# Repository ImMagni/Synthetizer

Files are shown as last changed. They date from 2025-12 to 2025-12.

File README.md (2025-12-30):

# Synthesizer 
A Synthesizer piano with three octaves that uses an Orpheus Pico, PCM5100 DAC, LM4810, and PAM8403 amplifiers.
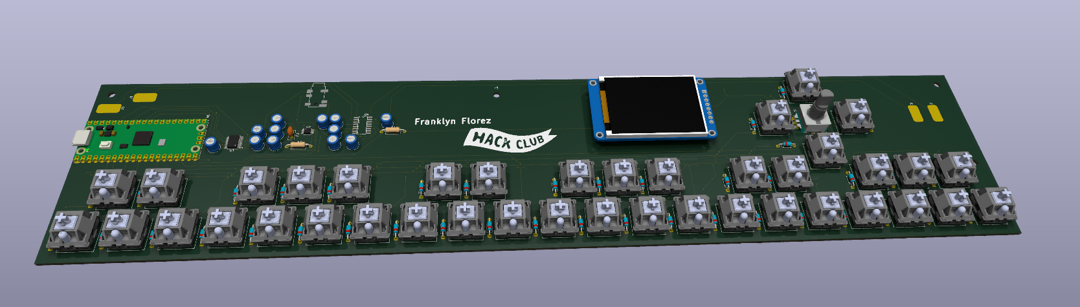
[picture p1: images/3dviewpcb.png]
 <br>

This project is a digital synthesizer keyboard capable of generating audio internally or outputting MIDI over USB. It features a screen-based user interface controlled through a rotary encoder and directional buttons.
## Features
- Volume control from the screen using a rotary encoder
- Selectable output modes: MIDI, Speakers, or Line output
- Three-octave keyboard
- Multiple waveform generation modes for audio
- Settings saves on memory
- On-screen menu system with directional navigation
- LCD feedback for current settings
## BOM
- 1× Orpheus_Pico (Raspberry Pi Pico)
- 5× Capacitor 1 µF
- 4× Capacitor 4.7 µF
- 1× Capacitor 0.1 µF
- 1× Capacitor 0.1 µF
- 2× Capacitor 10 µF
- 41× Diode 1N4148
- 1× screen ST7735R LCD
- 1× Jack audio 3.5 mm
- 2× Resistencia 10 kΩ
- 40× Cherry Switchs
- 1× Rotary Encoder with switch
- 1× PCM5100 DAC
- 1× LM4810
- 1x PAM8403
- 5x M3 Heatsets
- 5x M3x16 screws

Case|Schematic|Pcb
:-:|:-:|:-:|
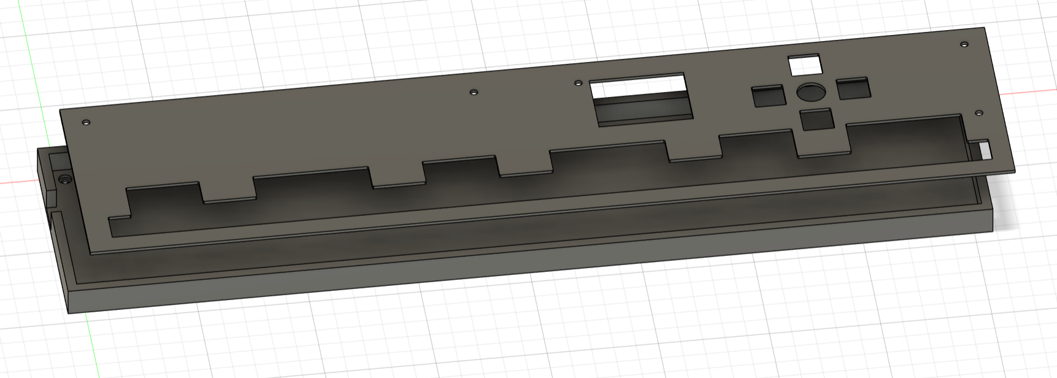
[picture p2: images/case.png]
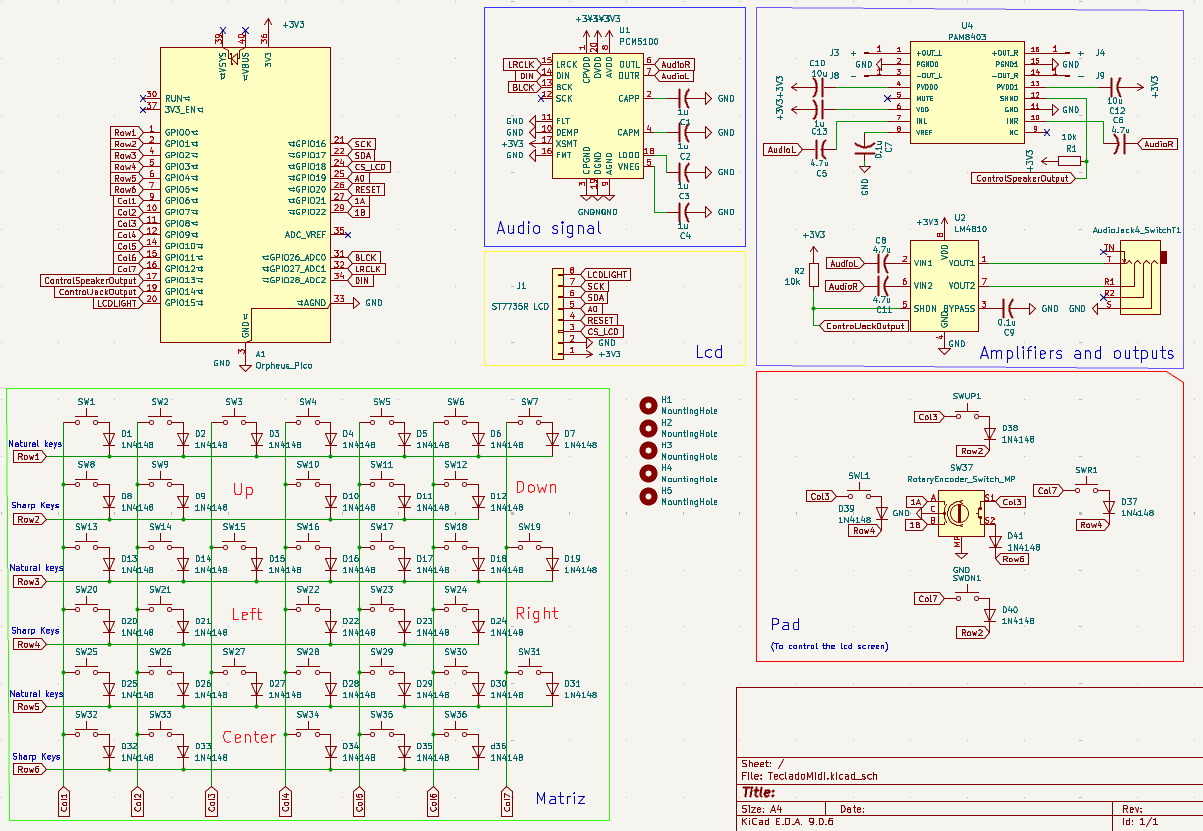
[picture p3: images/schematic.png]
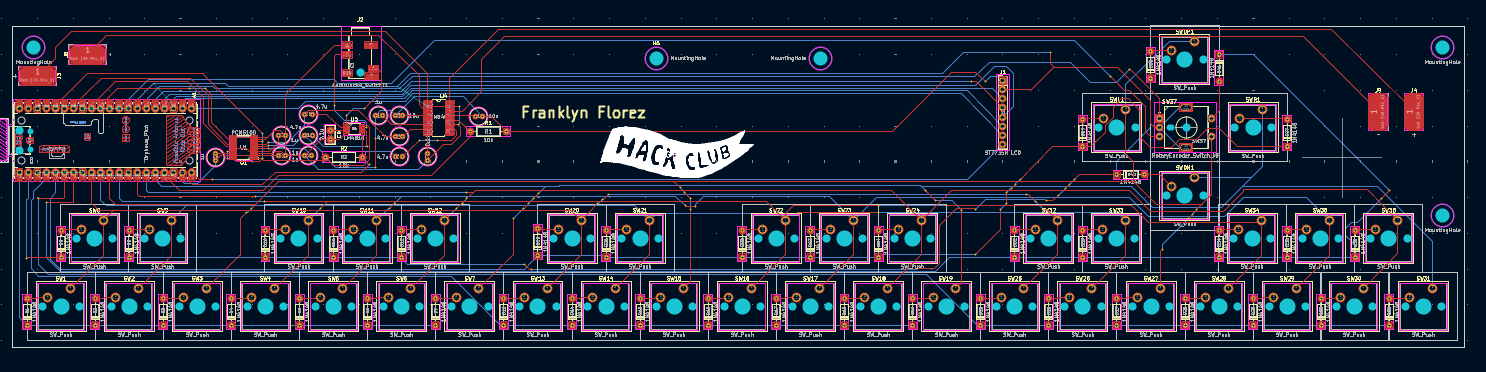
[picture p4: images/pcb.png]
|| 

-|-
:-:|:-:|
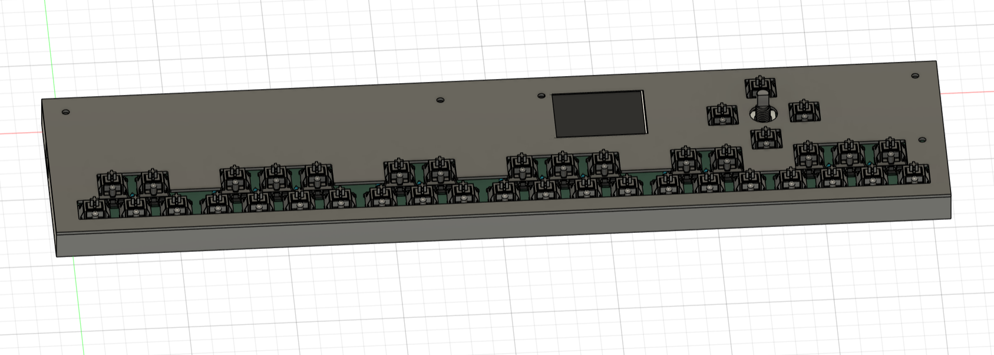
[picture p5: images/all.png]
|

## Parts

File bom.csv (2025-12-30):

Reference | Value | Footprint | Product Amount | Do i have it? | It comes in the kit? | Product Cost |  | link
Orpheus_Pico |  | Module:RaspberryPi_Pico_Common_Unspecified | 1 | No | Yes
Capacitor | 1u | Capacitor_THT:C_Radial_D5.0mm_H5.0mm_P2.00mm | 5 | No | Yes
Capacitor | 4.7u | Capacitor_THT:C_Radial_D5.0mm_H5.0mm_P2.00mm | 4 | No | Yes
Capacitor | 0.1u | Capacitor_THT:C_Radial_D5.0mm_H5.0mm_P2.00mm | 1 | No | Yes
Capacitor | 0.1u | Capacitor_THT:C_Disc_D5.0mm_W2.5mm_P2.50mm | 1 | No | Yes
Capacitor | 10u | Capacitor_THT:C_Radial_D5.0mm_H5.0mm_P2.00mm | 2 | No | Yes
1N4148 |  | Diode_THT:D_DO-35_SOD27_P7.62mm_Horizontal | 41 | No | Yes
ST7735R LCD |  | Connector_PinHeader_2.54mm:PinHeader_1x08_P2.54mm_Vertical | 1 | No | Yes
resistor | 10k | Resistor_THT:R_Axial_DIN0207_L6.3mm_D2.5mm_P10.16mm_Horizontal | 2 | No | Yes
Cherry Switches |  | Button_Switch_Keyboard:SW_Cherry_MX_1.00u_PCB | 40 | No | Yes
Keycaps |  | keyboard white keycaps | 40 | No | Yes
RotaryEncoder |  | Rotary_Encoder:RotaryEncoder_Alps_EC11E-Switch_Vertical_H20mm_MountingHoles | 1 | No | Yes
PCM5100 |  | Package_SO:TSSOP-20_4.4x6.5mm_P0.65mm | 1 | No | Yes
 |  | Speaker | 2 | Yes | No
LM4810 |  | Package_SO:TSSOP-8_3x3mm_P0.65mm | 1 | No | No | $0.40 |  | https://es.aliexpress.com/item/1005009657867113.html?curPageLogUid=Ha6Cjx350bAm
PAM8403 |  | PAM8403:SOP-16 | 1 | No | No | $0.98 | Comes in pack of 10, need 1 | https://es.aliexpress.com/item/1005004049958533.html?curPageLogUid=COpiZgxlrIOB
Audio Jack |  | Connector_Audio:Jack_3.5mm_PJ31060-I_Horizontal | 1 | No | No | $1.73 | Comes in pack of 10, need 1 | https://es.aliexpress.com/item/1005008729176265.html?curPageLogUid=a8f75ttgA6LR
PCB |  | PCB | 1 | No | No | $18.20 |  | jlcpcb
PCB shipping |  |  |  |  |  | $24.57
Aliexpress shipping |  |  |  |  |  | $6.86
 |  |  |  |  | Total | $52.74 | It doesnt include the 3d case ship

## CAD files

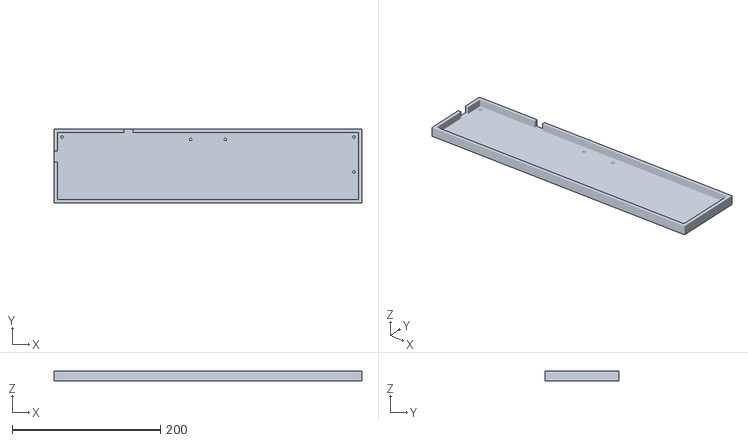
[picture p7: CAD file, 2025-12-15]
CAD/bottom case.stl
416.0 x 100.0 x 13.0

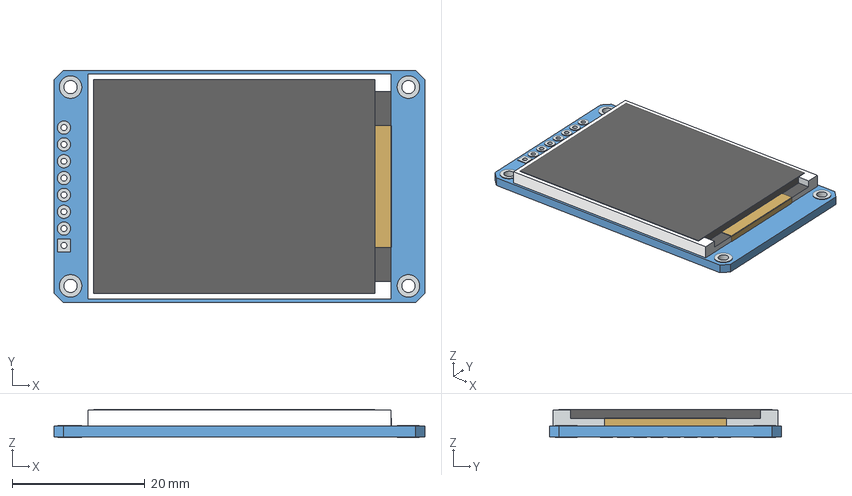
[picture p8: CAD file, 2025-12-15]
PCB/1-8-inches-128x160-rgb-tft-lcd-st7735-driver-1.snapshot.3/1.8_inches_128x160_RGB_TFT_LCD.stp
56.0 x 35.0 x 4.25 mm

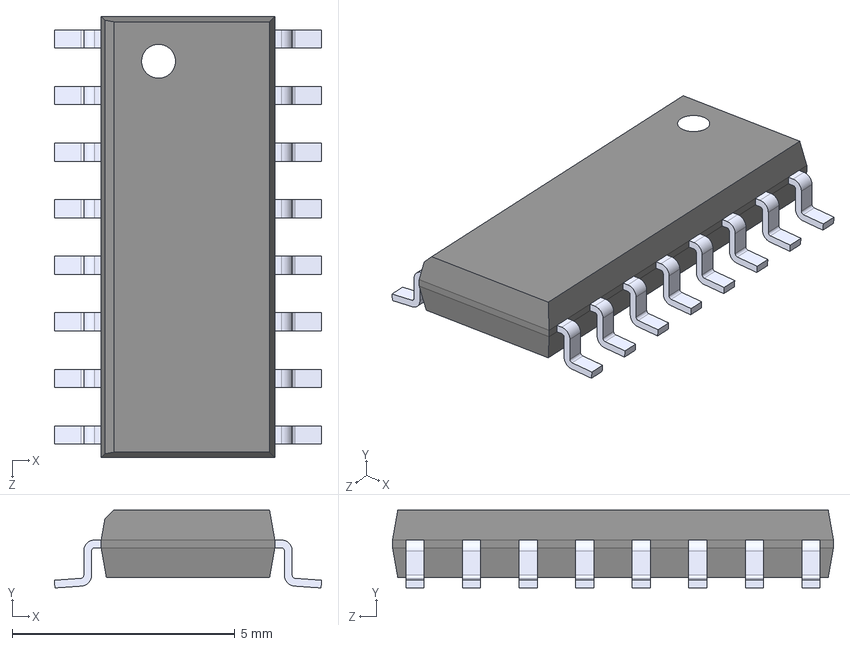
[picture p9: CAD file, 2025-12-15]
PCB/PAM8403/PAM8403.step
6.00 x 1.75 x 9.90 mm

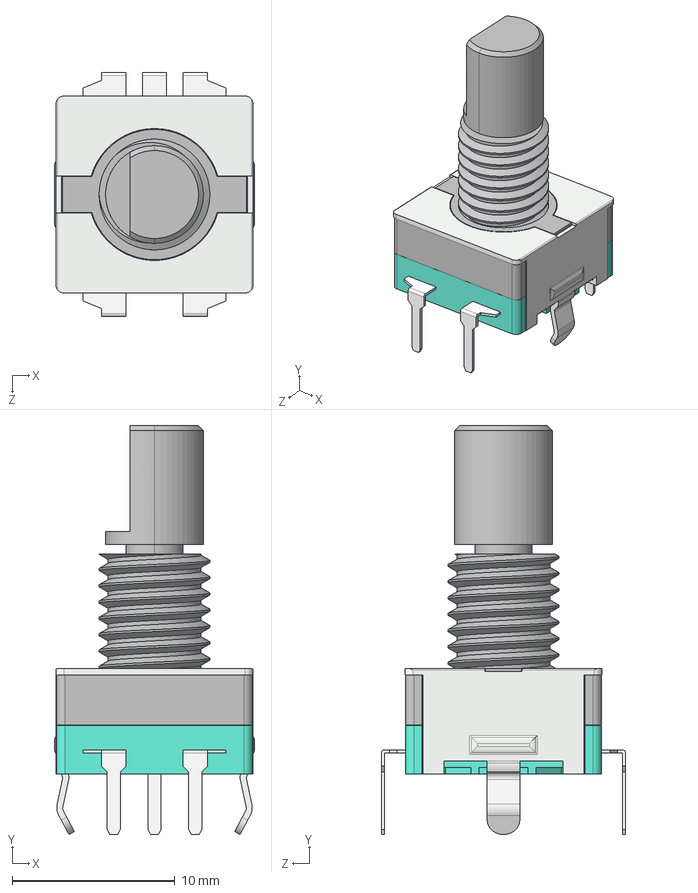
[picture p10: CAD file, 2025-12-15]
PCB/rotary-encoder-17.snapshot.2/旋转编码器.STEP
12.3 x 25.1 x 15.0 mm

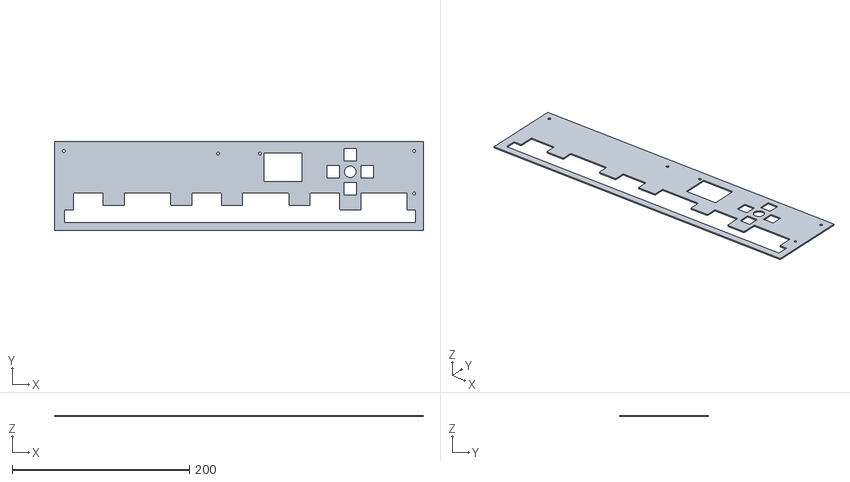
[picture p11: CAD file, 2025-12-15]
CAD/top case.stl
416.0 x 100.0 x 1.50

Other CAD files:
PCB/1-8-inches-128x160-rgb-tft-lcd-st7735-driver-1.snapshot.3/1.8_inches_128x160_RGB_TFT_LCD.ipt
PCB/rotary-encoder-17.snapshot.2/旋转编码器.SLDPRT

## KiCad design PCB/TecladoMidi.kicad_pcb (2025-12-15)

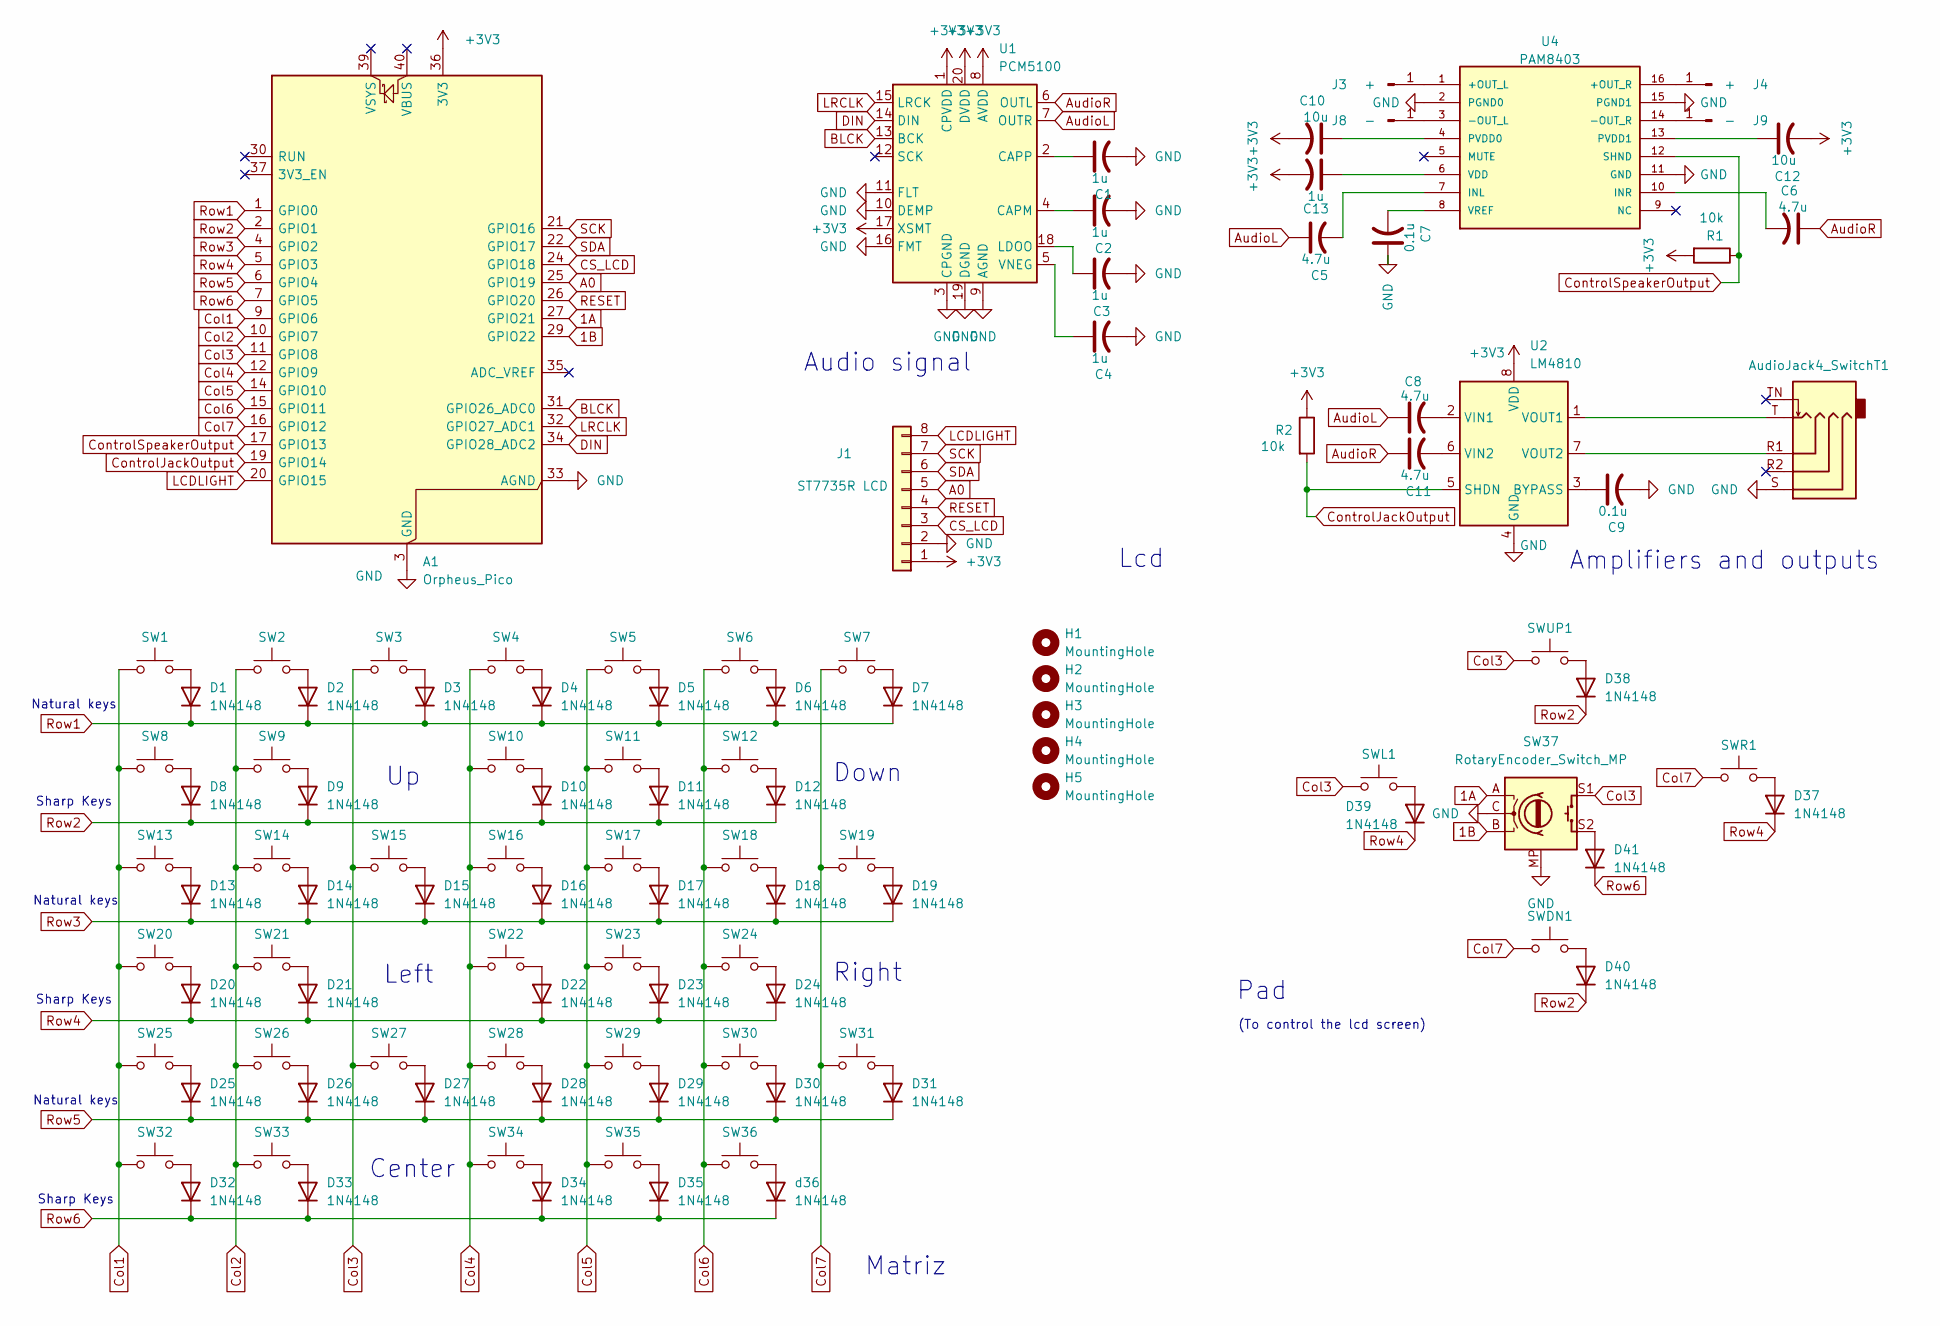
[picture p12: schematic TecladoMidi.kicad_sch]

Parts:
A1: Orpheus_Pico; RaspberryPi_Pico_Common_Unspecified
C1, C2, C3, C4, C13: 1u; C_Radial_D5.0mm_H5.0mm_P2.00mm
C5, C6, C8, C11: 4.7u; C_Radial_D5.0mm_H5.0mm_P2.00mm
C7: 0.1u; C_Radial_D5.0mm_H5.0mm_P2.00mm
C9: 0.1u; C_Disc_D5.0mm_W2.5mm_P2.50mm
C10, C12: 10u; C_Radial_D5.0mm_H5.0mm_P2.00mm
D1, D2, D3, D4, D5, D6, D7, D8, D9, D10, D11, D12, D13, D14, D15, D16, D17, D18, D19, D20, D21, D22, D23, D24, D25, D26, D27, D28, D29, D30, D31, D32, D33, D34, D35, D37, D38, D39, D40, D41: 1N4148; D_DO-35_SOD27_P7.62mm_Horizontal
H1, H2, H3, H4, H5: MountingHole; MountingHole_3.2mm_M3
J1: ST7735R LCD; PinHeader_1x08_P2.54mm_Vertical
J2: AudioJack4_SwitchT1; Jack_3.5mm_PJ31060-I_Horizontal
J3, J4: +; SolderWirePad_1x01_SMD_5x10mm
J8, J9: -; SolderWirePad_1x01_SMD_5x10mm
R1, R2: 10k; R_Axial_DIN0207_L6.3mm_D2.5mm_P10.16mm_Horizontal
SW1, SW2, SW3, SW4, SW5, SW6, SW7, SW8, SW9, SW10, SW11, SW12, SW13, SW14, SW15, SW16, SW17, SW18, SW19, SW20, SW21, SW22, SW23, SW24, SW25, SW26, SW27, SW28, SW29, SW30, SW31, SW32, SW33, SW34, SW35, SW36: SW_Push; SW_Cherry_MX_1.00u_PCB
SW37: RotaryEncoder_Switch_MP; RotaryEncoder_Alps_EC11E-Switch_Vertical_H20mm_MountingHoles
SWDN1: SW_Push; SW_Cherry_MX_1.00u_PCB
SWL1: SW_Push; SW_Cherry_MX_1.00u_PCB
SWR1: SW_Push; SW_Cherry_MX_1.00u_PCB
SWUP1: SW_Push; SW_Cherry_MX_1.00u_PCB
U1: PCM5100; TSSOP-20_4.4x6.5mm_P0.65mm
U2: LM4810; TSSOP-8_3x3mm_P0.65mm
U4: PAM8403; SOP-16
d36: 1N4148; D_DO-35_SOD27_P7.62mm_Horizontal

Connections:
1A: A1.27 (GPIO21), SW37.A
1B: A1.29 (GPIO22), SW37.B
+3V3: A1.36 (3V3), C10.2, C12.2, C13.2, J1.1, R1.2, R2.1, U1.1 (CPVDD), U1.8 (AVDD), U1.17 (XSMT), U1.20 (DVDD), U2.8 (VDD)
A0: A1.25 (GPIO19), J1.5
AudioL: C5.1, C8.1, U1.7 (OUTR)
AudioR: C6.1, C11.1, U1.6 (OUTL)
BLCK: A1.31 (GPIO26_ADC0), U1.13 (BCK)
CS_LCD: A1.24 (GPIO18), J1.3
Col1: A1.9 (GPIO6), SW1.1, SW8.1, SW13.1, SW20.1, SW25.1, SW32.1
Col2: A1.10 (GPIO7), SW2.1, SW9.1, SW14.1, SW21.1, SW26.1, SW33.1
Col3: A1.11 (GPIO8), SW3.1, SW15.1, SW27.1, SW37.S1, SWL1.1, SWUP1.1
Col4: A1.12 (GPIO9), SW4.1, SW10.1, SW16.1, SW22.1, SW28.1, SW34.1
Col5: A1.14 (GPIO10), SW5.1, SW11.1, SW17.1, SW23.1, SW29.1, SW35.1
Col6: A1.15 (GPIO11), SW6.1, SW12.1, SW18.1, SW24.1, SW30.1, SW36.1
Col7: A1.16 (GPIO12), SW7.1, SW19.1, SW31.1, SWDN1.1, SWR1.1
ControlJackOutput: A1.19 (GPIO14), R2.2, U2.5 (SHDN)
ControlSpeakerOutput: A1.17 (GPIO13), R1.1, U4.12 (SHND)
DIN: A1.34 (GPIO28_ADC2), U1.14 (DIN)
GND: A1.3 (GND), A1.8 (GND), A1.13 (GND), A1.18 (GND), A1.23 (GND), A1.28 (GND), A1.33 (AGND), A1.38 (GND), C1.2, C2.2, C3.2, C4.2, C7.1, C9.2, J1.2, J2.S, SW37.C, SW37.MP, U1.3 (CPGND), U1.9 (AGND), U1.10 (DEMP), U1.11 (FLT), U1.16 (FMT), U1.19 (DGND), U2.4 (GND), U4.2 (PGND0), U4.11 (GND), U4.15 (PGND1)
LCDLIGHT: A1.20 (GPIO15), J1.8
LRCLK: A1.32 (GPIO27_ADC1), U1.15 (LRCK)
unnamed: D1.2 (A), SW1.2
unnamed: D2.2 (A), SW2.2
unnamed: D3.2 (A), SW3.2
unnamed: D4.2 (A), SW4.2
unnamed: D5.2 (A), SW5.2
unnamed: D6.2 (A), SW6.2
unnamed: D7.2 (A), SW7.2
unnamed: D8.2 (A), SW8.2
unnamed: D9.2 (A), SW9.2
unnamed: D10.2 (A), SW10.2
unnamed: D11.2 (A), SW11.2
unnamed: D12.2 (A), SW12.2
unnamed: D13.2 (A), SW13.2
unnamed: D14.2 (A), SW14.2
unnamed: D15.2 (A), SW15.2
unnamed: D16.2 (A), SW16.2
unnamed: D17.2 (A), SW17.2
unnamed: D18.2 (A), SW18.2
unnamed: D19.2 (A), SW19.2
unnamed: D20.2 (A), SW20.2
unnamed: D21.2 (A), SW21.2
unnamed: D22.2 (A), SW22.2
unnamed: D23.2 (A), SW23.2
unnamed: D24.2 (A), SW24.2
unnamed: D25.2 (A), SW25.2
unnamed: D26.2 (A), SW26.2
unnamed: D27.2 (A), SW27.2
unnamed: D28.2 (A), SW28.2
unnamed: D29.2 (A), SW29.2
unnamed: D30.2 (A), SW30.2
unnamed: D31.2 (A), SW31.2
unnamed: D32.2 (A), SW32.2
unnamed: D33.2 (A), SW33.2
unnamed: D34.2 (A), SW34.2
unnamed: D35.2 (A), SW35.2
unnamed: D37.2 (A), SWR1.2
unnamed: D38.2 (A), SWUP1.2
unnamed: D39.2 (A), SWL1.2
unnamed: D40.2 (A), SWDN1.2
unnamed: D41.2 (A), SW37.S2
unnamed: J3.1, U4.1 (+OUT_L)
unnamed: J4.1, U4.16 (+OUT_R)
unnamed: J8.1, U4.3 (-OUT_L)
unnamed: J9.1, U4.14 (-OUT_R)
unnamed: C2.1, U1.4 (CAPM)
unnamed: C1.1, U1.2 (CAPP)
unnamed: C3.1, U1.18 (LDOO)
unnamed: C4.1, U1.5 (VNEG)
unnamed: C9.1, U2.3 (BYPASS)
unnamed: C8.2, U2.2 (VIN1)
unnamed: C11.2, U2.6 (VIN2)
unnamed: J2.T, U2.1 (VOUT1)
unnamed: J2.R1, U2.7 (VOUT2)
unnamed: C5.2, U4.7 (INL)
unnamed: C6.2, U4.10 (INR)
unnamed: C10.1, U4.4 (PVDD0)
unnamed: C12.1, U4.13 (PVDD1)
unnamed: C13.1, U4.6 (VDD)
unnamed: C7.2, U4.8 (VREF)
unnamed: SW36.2, d36.2 (A)
RESET: A1.26 (GPIO20), J1.4
Row1: A1.1 (GPIO0), D1.1 (K), D2.1 (K), D3.1 (K), D4.1 (K), D5.1 (K), D6.1 (K), D7.1 (K)
Row2: A1.2 (GPIO1), D8.1 (K), D9.1 (K), D10.1 (K), D11.1 (K), D12.1 (K), D38.1 (K), D40.1 (K)
Row3: A1.4 (GPIO2), D13.1 (K), D14.1 (K), D15.1 (K), D16.1 (K), D17.1 (K), D18.1 (K), D19.1 (K)
Row4: A1.5 (GPIO3), D20.1 (K), D21.1 (K), D22.1 (K), D23.1 (K), D24.1 (K), D37.1 (K), D39.1 (K)
Row5: A1.6 (GPIO4), D25.1 (K), D26.1 (K), D27.1 (K), D28.1 (K), D29.1 (K), D30.1 (K), D31.1 (K)
Row6: A1.7 (GPIO5), D32.1 (K), D33.1 (K), D34.1 (K), D35.1 (K), D41.1 (K), d36.1 (K)
SCK: A1.21 (GPIO16), J1.7
SDA: A1.22 (GPIO17), J1.6

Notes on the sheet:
Matriz
Right
Sharp Keys
(To control the lcd screen)
Amplifiers and outputs
Down
Audio signal
Lcd
Natural keys
Pad
Center
Left

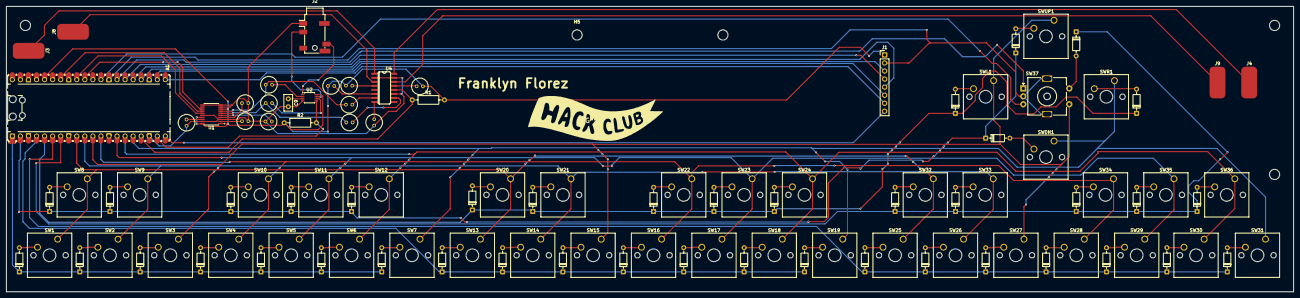
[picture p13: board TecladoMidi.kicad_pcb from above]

Board: 2 copper layers, 406.0 x 90.0 mm, 112 parts (0 on the bottom side), 90 nets.

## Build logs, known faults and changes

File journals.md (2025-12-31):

<!--
  This journal is auto generated by Hack Club Blueprint.
-->

## 12/9/2025 - research  

_Time spent: 3.0h_  

okay I want do a a three(21 notes and 15 sharp notes) or four(28 notes and 20 sharp notes) octaves syntethizer so it will have 36 or 48 switches, i want it to have built in speaker powered by DIP LM4861 or Pam8304 and one output auxiliar output powered by the LM4810, i also want one slider to change octaves and one for the volume, and i found this library to convert i2s to analog and i think that i can add effects like sustain.

 https://github.com/elehobica/pico_audio_i2s_32b



i also learned a lot about audio generation, conversion from digital to analog, i learned the datashets of lm4810, pam5100 and lm4861 and saw some tutorials in youtube about them.  

## 12/11/2025 6 PM - making schematic  

_Time spent: 2.4h_  

okay i first created the switch matrix with three octaves (6 rows and 7 columns) i wired them to the rasp berry pico



after that i wired the lcd screen(i think ill use a pot with a npn transistor to controll the back light, and i searched how to wire the pcm5100 because in the tutorial they didn't explain how to connect some pins and it took a lot of time



and i added two rotary encoders


## 12/11/2025 8 PM - ended schematics  

_Time spent: 1.6h_  

changed Pam8304 for Pam0303 and i researched how to connect pins on pam8403 and lm4810, i connected first to two stereo speakers and second one to a 3mm jack and added one switch to switch with output will be used


then i created a pad to navigate on the menu, (now ill change the volume, effects, and octaves from there) and i think the schematic is ended



## 12/12/2025 9 AM - Final schematic  

_Time spent: 1.0h_  

i fixed some errors, deleted the physical switch, organized and verified everything with ERC and Ia, so i think it will work perfectly i also viewed datashets of pam8403, and lm4810 to make sure it is right connected.





## 12/12/2025 3 PM - Ended pcb  

_Time spent: 3.8h_  

First, i organized the switches in a piano configuration. then i routed the PCM5100, LM4810, PAM8403, and the capacitors. after that, I routed the switches and diodes. I deleted unnecessary text, routed the LCD screen, verified everything, and tried to make the pcb compact.





It wasn’t that difficult, but it was time-consuming.  

## 12/13/2025 - created 3d case  

_Time spent: 3.2h_  

i added one extra mounting hole because i think i will need to divide in two parts the 3d model because its size is more than 256 in x axe, and i started creating the 3d case following the hackpad case guide, but with wider borders and with the m3 head inserts below the pcb 
and i made two holes for the usb and the jack output 



after that i started creating the top plate using maths and the plate from hackpad tutorial







it looks very easy to do but it was harder for me. i’m very bad at 3D design lol.  

## 12/14/2025 - code  

_Time spent: 0.2h_  

okay, i think that this will be the last journal, i learned a lot in the path and i want to say that sorry if my english is bad, my native language is spanish not english and it is a bit bad but i try my best to write it.

and the last changes i made for this are that i added silkscreen,


then i created the code based on the guide and using ChatGPT (ill upgrade it and add all the functions i want to add once the parts arrive, because it’ll be easier to test)



i also made the .bom and uploaed all files to github

## 12/30/2025 - Changed code, bom and readme  

_Time spent: 2.7h_  

The first code I made already had basic audio generation, keyboard scanning, and screen setup, but it didnt had a proper menu system and some parts were messy. The reason for that is because I planned to adjust and improve the code once the kit and the PCB arrived to test it easier, but I had to do those changes earlier.

The first main improvement was clearly defining different states for the menu, like volume control, output selection, octave selection, and wave selection. I also added a debounce of about 0.15 seconds to avoid random or unintended button presses

I added visual feedback on the lcd(+1 octaves, 100% volumen, wave type). The menu now shows a 2×2 layout and the selected option is highlighted, so it’s easier to see where you are when navigating the menu using the keypad and u use the rotary encoder switch to select the option

I added settings storage using the microcontroller.nvm(Non-Volatile Memory). Things like volume, output mode, octave offset, and wave type are saved and loaded on startup, so the synthesizer keeps its settings

The output handling was improved so only one output is active at a time. when switching between midi, speakers, or line out, the audio is muted to avoid clicks or rare sounds and to prevent conflicts between outputs.

And to clarify i only need to buy the parts that are marked as they dont come in the kit and that i dont have in the bom file(i edited it), so i think i dont need to send screnshots of these parts because they come in the kit, and i think that the project actually is tier 3 not tier 4.



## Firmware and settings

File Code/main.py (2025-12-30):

import board, digitalio, math, array, time
import audiobusio, displayio, busio, terminalio
import keypad, microcontroller, usb_midi, adafruit_midi
from adafruit_midi.note_on import NoteOn
from adafruit_midi.note_off import NoteOff
from fourwire import FourWire
from adafruit_st7735r import ST7735R
from adafruit_display_text import label

STATE_MENU   = 0
STATE_VOLUME = 1
STATE_OUTPUT = 2
STATE_OCTAVE = 3
STATE_WAVE   = 4

OUTPUT_LINE = 0
OUTPUT_SPK  = 1
OUTPUT_MIDI = 2

WAVE_SINE   = 0
WAVE_SQUARE = 1

DEBOUNCE_TIME = 0.15

KEY_UP    = 9
KEY_DOWN  = 13
KEY_LEFT  = 23
KEY_RIGHT = 27
KEY_CLICK = 37
NAV_KEYS = (KEY_UP, KEY_DOWN, KEY_LEFT, KEY_RIGHT, KEY_CLICK)

if microcontroller.nvm[0] == 0xAA:
    VOLUME = microcontroller.nvm[1] / 100
    output_mode = microcontroller.nvm[2]
    octave_offset = microcontroller.nvm[3]
    wave_type = microcontroller.nvm[4]
else:
    VOLUME = 0.4
    output_mode = OUTPUT_LINE
    octave_offset = 0
    wave_type = WAVE_SINE
    microcontroller.nvm[0] = 0xAA

amp_speaker = digitalio.DigitalInOut(board.GP13)
amp_jack    = digitalio.DigitalInOut(board.GP14)
amp_speaker.direction = amp_jack.direction = digitalio.Direction.OUTPUT

displayio.release_displays()
spi = busio.SPI(clock=board.GP16, MOSI=board.GP17)
display_bus = FourWire(spi, command=board.GP19,
                       chip_select=board.GP18, reset=board.GP20)
display = ST7735R(display_bus, width=128, height=160, rotation=270)

root = displayio.Group()
display.root_group = root

bg = displayio.Bitmap(128, 160, 1)
pal = displayio.Palette(1)
pal[0] = 0x000000
root.append(displayio.TileGrid(bg, pixel_shader=pal))

title = label.Label(terminalio.FONT, text="ORPHEUS", color=0x00FF00, x=30, y=10)
status = label.Label(terminalio.FONT, text="", color=0xFFFFFF, x=10, y=40)
root.append(title)
root.append(status)

menu_labels = []
menu_texts = ["VOL", "OUT", "OCT", "WAVE"]

keys = keypad.KeyMatrix(
    rows=(board.GP0, board.GP1, board.GP2, board.GP3, board.GP4, board.GP5),
    columns=(board.GP6, board.GP7, board.GP8, board.GP9,
             board.GP10, board.GP11, board.GP12)
)

encoder = keypad.IncrementalEncoder(board.GP21, board.GP22)

audio = audiobusio.I2SOut(
    bit_clock=board.GP26,
    word_select=board.GP27,
    data=board.GP28
)

SAMPLE_RATE = 22050
BUFFER = array.array("h", [0]*256)
phase = 0
phase_inc = 0
sine = [int(32767 * math.sin(2*math.pi*i/256)) for i in range(256)]

midi = adafruit_midi.MIDI(
    midi_out=usb_midi.ports[1],
    out_channel=0
)

current_note = None

def note_to_freq(note):
    return 440 * (2 ** ((note - 69) / 12))

def update_output():
    global phase_inc
    phase_inc = 0
    amp_jack.value    = (output_mode == OUTPUT_LINE)
    amp_speaker.value = (output_mode == OUTPUT_SPK)

def save_settings():
    microcontroller.nvm[1] = int(VOLUME * 100)
    microcontroller.nvm[2] = output_mode
    microcontroller.nvm[3] = octave_offset
    microcontroller.nvm[4] = wave_type

def draw_status(text):
    status.text = text

def draw_menu():
    global menu_labels
    for lbl in menu_labels:
        root.remove(lbl)
    menu_labels.clear()

    x_pos = [10, 70]
    y_pos = [60, 90]

    for i, text in enumerate(menu_texts):
        color = 0x00FF00 if i == menu_index else 0xFFFFFF
        lbl = label.Label(terminalio.FONT, text=text, color=color,
                          x=x_pos[i % 2], y=y_pos[i // 2])
        root.append(lbl)
        menu_labels.append(lbl)

ui_state = STATE_MENU
menu_index = 0
last_input = 0
draw_menu()

while True:
    now = time.monotonic()

    event = keys.events.get()
    if event:

        if event.pressed and event.key_number in NAV_KEYS:
            if now - last_input > DEBOUNCE_TIME:
                last_input = now

                if event.key_number == KEY_CLICK:
                    if ui_state == STATE_MENU:
                        ui_state = [STATE_VOLUME, STATE_OUTPUT,
                                    STATE_OCTAVE, STATE_WAVE][menu_index]
                    else:
                        ui_state = STATE_MENU
                        save_settings()
                        draw_menu()

                elif ui_state == STATE_MENU:
                    if event.key_number == KEY_UP:
                        menu_index = max(0, menu_index - 2)
                    elif event.key_number == KEY_DOWN:
                        menu_index = min(3, menu_index + 2)
                    elif event.key_number == KEY_LEFT:
                        menu_index = max(0, menu_index - 1)
                    elif event.key_number == KEY_RIGHT:
                        menu_index = min(3, menu_index + 1)
                    draw_menu()

        elif event.pressed:
            note = 48 + event.key_number + octave_offset * 12
            phase_inc = int(note_to_freq(note) * 256 / SAMPLE_RATE)

            if output_mode == OUTPUT_MIDI:
                midi.send(NoteOn(note, int(VOLUME * 127)))
                current_note = note

        elif event.released:
            if current_note is not None:
                midi.send(NoteOff(current_note, 0))
                current_note = None
            phase_inc = 0

    enc = encoder.events.get()
    if enc and now - last_input > DEBOUNCE_TIME:
        last_input = now

        if ui_state == STATE_VOLUME:
            VOLUME = max(0, min(0.8, VOLUME + enc.position_change * 0.05))
            draw_status(f"VOL {int(VOLUME*100)}%")

        elif ui_state == STATE_OUTPUT:
            output_mode = (output_mode + enc.position_change) % 3
            update_output()
            draw_status(["LINE","SPK","MIDI"][output_mode])

        elif ui_state == STATE_OCTAVE:
            octave_offset = max(-2, min(2, octave_offset + enc.position_change))
            draw_status(f"OCT {octave_offset}")

        elif ui_state == STATE_WAVE:
            wave_type = (wave_type + enc.position_change) % 2
            draw_status(["SINE","SQUARE"][wave_type])

    if output_mode != OUTPUT_MIDI:
        for i in range(len(BUFFER)):
            phase = (phase + phase_inc) & 0xFF
            BUFFER[i] = int(sine[phase] * VOLUME)
        audio.write(BUFFER)
